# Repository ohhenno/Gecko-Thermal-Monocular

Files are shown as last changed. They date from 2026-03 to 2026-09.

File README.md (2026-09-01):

# Gecko 256

The Gecko is an open-source thermal monocular featuring the Mini2 256p thermal core, digital zoom, and video recording capability. Special thanks to LupasWorax Gremlin and [JacobOTW](https://github.com/Jacob-OTW/BCOTI/tree/V2_Beta?tab=readme-ov-file) .

The hardware platform is built around:
- HdanieeCamera Core
- ESP32 UART/GPIO Controls  
- 0.39" micro OLED display  
- NP18 lens  

---

## 🧩 Parts Checklist

| ✓ | Component | Notes | Price (USD) | Link |
|--|---|---|---|---|
| ☐ | **Thermal Core (Mini2 256)** | Gecko Variant | $120 | https://shorturl.at/Mn3Rv |
| ☐ | **Thermal Core (P6 640)** | TAC-640 Variant | $420 | https://www.hdaniee.com/p6-uc-series.html |
| ☐ | **0.39" OLED Display** | Main display + driver | $110 | https://www.aliexpress.us/item/3256809119244467.html |
| ☐ | **NP18 Lens** | Optics | $60 | https://www.aliexpress.us/item/3256808208343549.html |
| ☐ | **ESP32-C3** | Main controller | $1 | https://www.aliexpress.us/item/3256808855552297.html |
| ☐ | **5V Boost Converter** | Steps battery → 5V | $2 | https://www.amazon.com/dp/B0836J8LR4 |
| ☐ | **18350 Battery** | Power source | $15 | https://amazon.com/dp/B07QDDS64F |
| ☐ | **Battery Contacts** | Spring terminals | $5 | https://amazon.com/dp/B0FSDNXKJY |
| ☐ | **Rotary Pot (20k)** | Brightness / contrast control | $2 | https://www.aliexpress.us/item/3256803337433740.html |
| ☐ | **Buttons (x3)** | Zoom / Mode / Record | $2 | https://www.aliexpress.us/item/3256806708603327.html |
| ☐ | **Runcam DVR (Optional)**  | Recording | $30 | https://www.aliexpress.us/item/3256809185467125.html |
| ☐ | **MicroSD Extender** | Required for DVR | $10 | https://amazon.com/dp/B0D7YZ5PG3 |
| ☐ | **M2.5 x 6 Bolts** | Mounting hardware | $2 | https://amazon.com/dp/B0GCSRG1WD |
| ☐ | **Heat Set Inserts** | Threaded inserts | $10 | [https://amazon.com/dp/B0D7YZ5PG3](https://shorturl.at/LMswM) |
| ☐ | **Silicone Wire** | Internal wiring | $6 | https://amazon.com/dp/B01KQ2JNLI |

---

### 💰 Estimated Build Cost

- **Gecko (Mini2 build):**  
  $335  

- **TAC-640 (P6 build):**  
  $635  

- **With DVR (adds DVR + MicroSD extender):**  
  $40  

---

## 📷 Device Overview







---

## ⚡ Power-On Behavior

Turn the potentiometer fully clockwise to power on the device.

- **System initialization time:** ~6 seconds  

### Default Image Settings
- Brightness: 70  
- Contrast: 64  
- Enhancement: 80  
- Denoise: 40  
- Zoom: 1.0×  
- Palette: White Hot  
- Automatic calibration (NUC): every 60 seconds  

---

## 🎮 Controls Overview

### Buttons
- **Zoom Button** — front-most button  
- **Multi Button** — center button  
- **Record Button** — rear button  

### Analog Control
- **Rotary Knob (Potentiometer)** — controls brightness and contrast  

---

## 🔍 Zoom & OLED Brightness

### Zoom Control
- **Single Press:**  
  Cycles zoom levels  
  `1.0× → 2.0× → 4.0× → repeat`

### OLED Brightness
- **Hold Zoom (~1 second):**  
  Increase brightness (continues stepping every ~1s)

- **Double Tap Zoom:**  
  Decrease brightness  

---

## 🎨 Palette Control

- **Multi Button (Short Press):**  
  Cycles through palettes:
  - White Hot  
  - Black Hot  
  - Rainbow  
  - Green Hot  
  - Red Hot  
  - Iron Red  

---

## 🎛️ Image Adjustment

- **Knob (Normal):**  
  Adjust brightness  

- **Hold Multi + Turn Knob:**  
  Adjust contrast  

---

## 🔴 Recording Feedback

- **Record Button:**  
  Toggles external DVR recording  

### Visual Feedback (Palette Flash)
- Start recording → **3 slow flashes**  
- Stop recording → **5 fast flashes**  

---

## 🧊 Calibration (NUC)

### Manual Calibration
- Hold **Multi button for 3 seconds**
  - Image briefly freezes  
  - Sensor recalibrates  
  - Fixed-pattern noise reduced  

### Automatic Calibration
- Runs every **60 seconds**  

---

## ⚡ Quick Reference

<table>
<tr>
<td valign="top">

| Action | Result |
|---|---|
| Zoom press | Change zoom |
| Zoom hold | Increase OLED brightness |
| Zoom double tap | Decrease OLED brightness |
| Multi press | Cycle palettes |
| Multi hold | Trigger NUC calibration |
| Knob | Adjust brightness |
| Multi + knob | Adjust contrast |
| Record press | Toggle recording |

</td>
<td valign="top">

<pre>
        Button Diagram

        [ Camera Side ]
               ↑
           ┌─────────┐
           │   ◉     │   ZOOM (Front)
           │         │
           │   ◉     │   MODE / MULTI
           │         │
           │   ◉     │   RECORD (Rear)
           └─────────┘
               ↓
        [ Ocular Side ]
</pre>

</td>
</tr>
</table>

---

## 🧠 System Diagram / Reference





---

Battery Life 1hr 26mins:


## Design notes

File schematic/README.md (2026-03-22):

The DVR is optional, its reduces the battery life by a non zero amount.

Pay special attention when wiring up the battery ground and general ground they are different nets.

Pay special attention of you are using a different 10 pin connector for the OLED board as they could be flipped.



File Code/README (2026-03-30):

Flash the ESP32-C3 Super Mini via https://esptool.spacehuhn.com/

Hold BOOT
Plug in USB
Release BOOT

Click Connect → select ESP32 serial port

Load files with offsets:

0x0 → bootloader.bin
0x8000 → partition-table.bin
0x10000 → gecko.bin

Click ERASE
Click PROGRAM

Done.

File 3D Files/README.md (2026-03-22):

Print these at 0.16 layer height in PETG for best results.



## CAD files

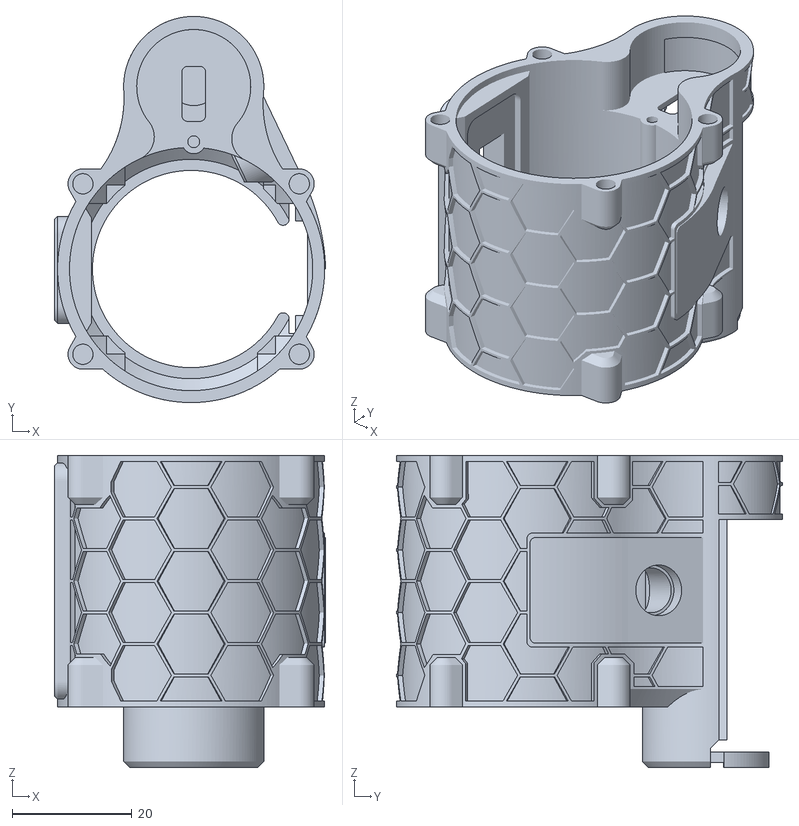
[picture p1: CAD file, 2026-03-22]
3D Files/thermal main body.stl
45.4 x 64.6 x 52.2

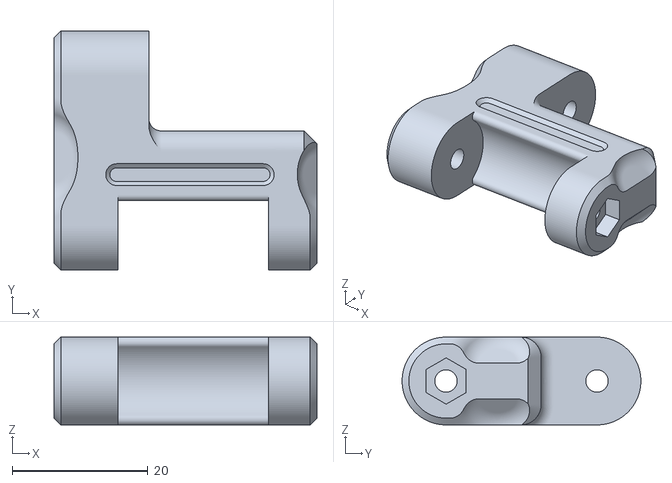
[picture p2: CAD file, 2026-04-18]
3D Files/J_ARM_elbow.stl
38.7 x 35.1 x 12.9

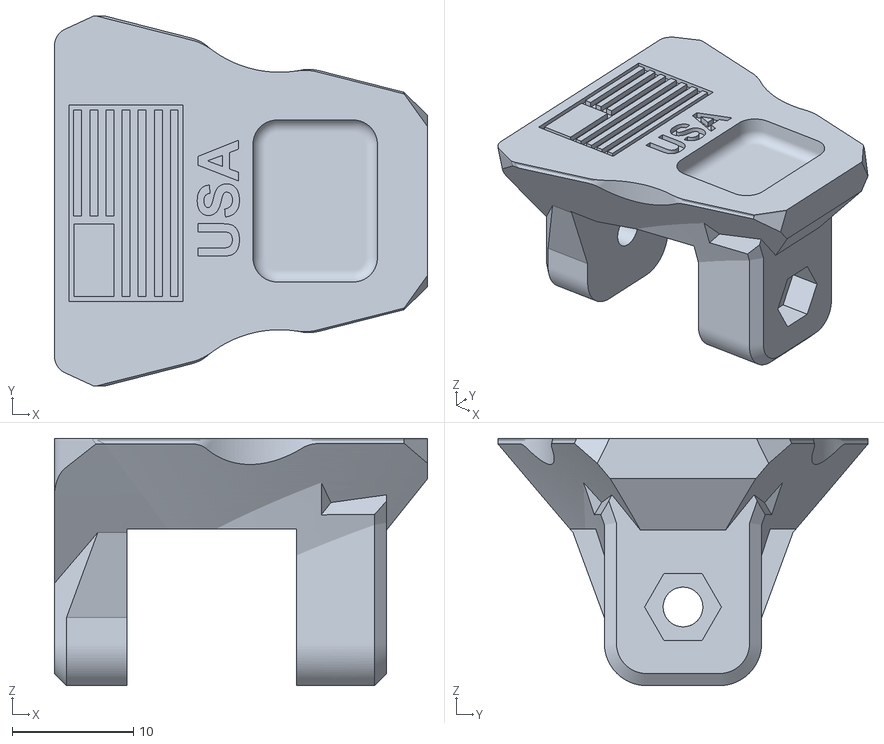
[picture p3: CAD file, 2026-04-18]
3D Files/J_ARM_dovetail.stl
30.8 x 30.6 x 20.4

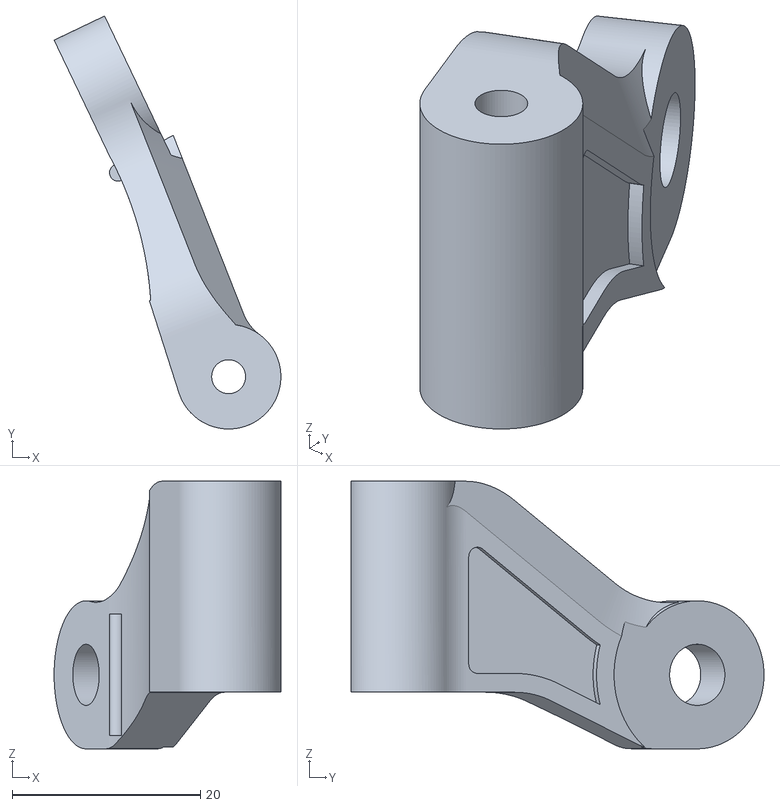
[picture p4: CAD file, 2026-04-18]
3D Files/J_ARM.stl
24.1 x 43.8 x 28.4

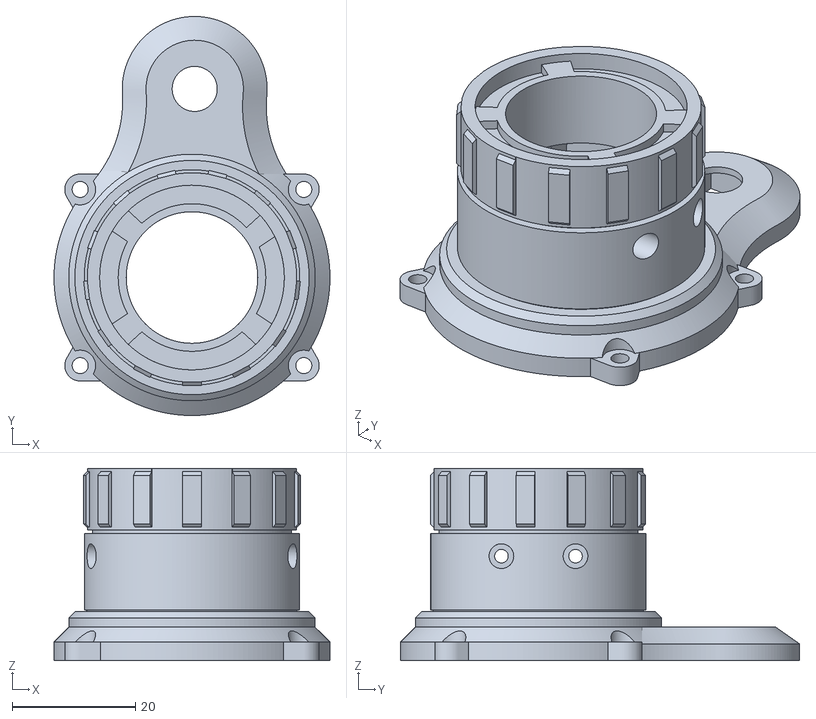
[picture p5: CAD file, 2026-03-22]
3D Files/thermal body camera.stl
44.7 x 64.6 x 31.1

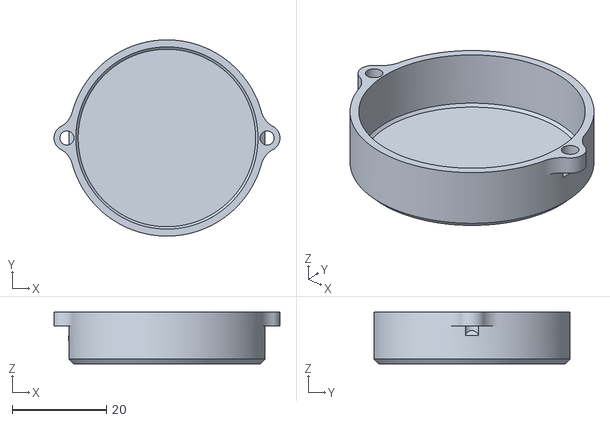
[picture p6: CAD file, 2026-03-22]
3D Files/lens cap.stl
48.0 x 41.7 x 11.0

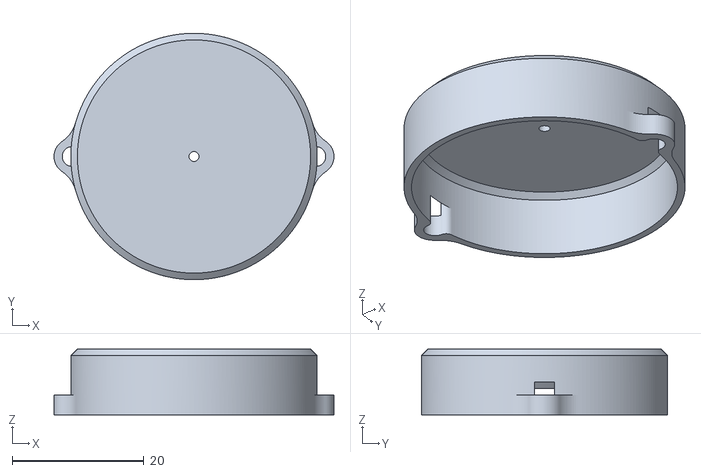
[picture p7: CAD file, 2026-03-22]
3D Files/camera cap.stl
42.4 x 37.3 x 10.0

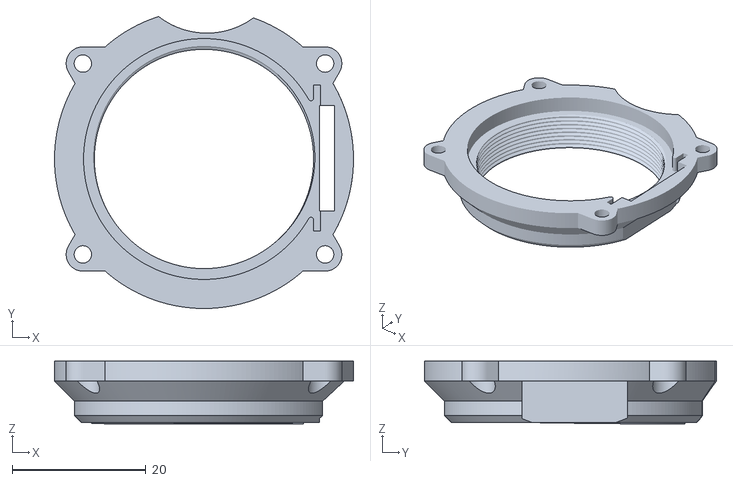
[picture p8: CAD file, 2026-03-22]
3D Files/thermal body np18.stl
44.7 x 43.6 x 9.39

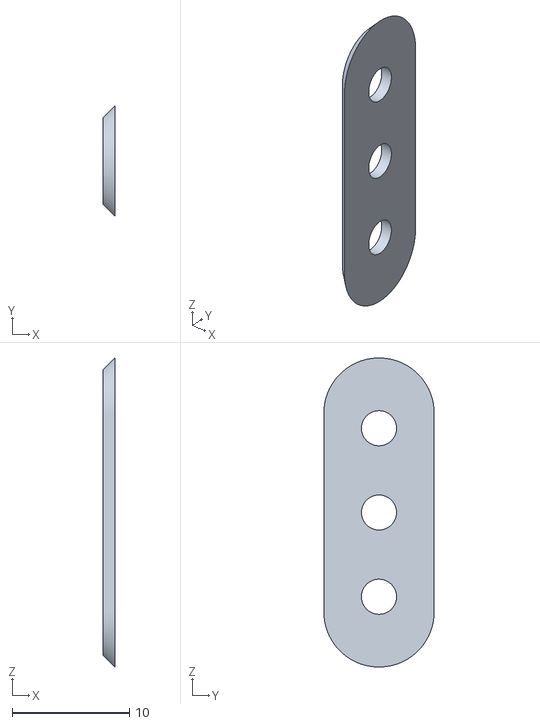
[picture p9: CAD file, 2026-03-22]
3D Files/button cover.stl
1.00 x 9.43 x 26.4

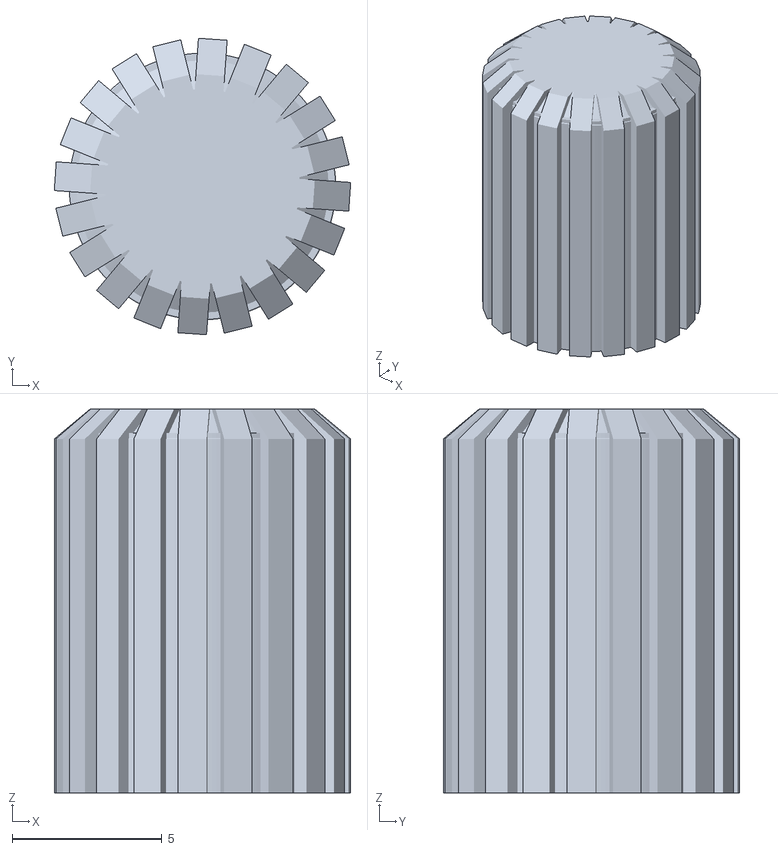
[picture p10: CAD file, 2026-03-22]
3D Files/knob.stl
9.88 x 9.88 x 12.8

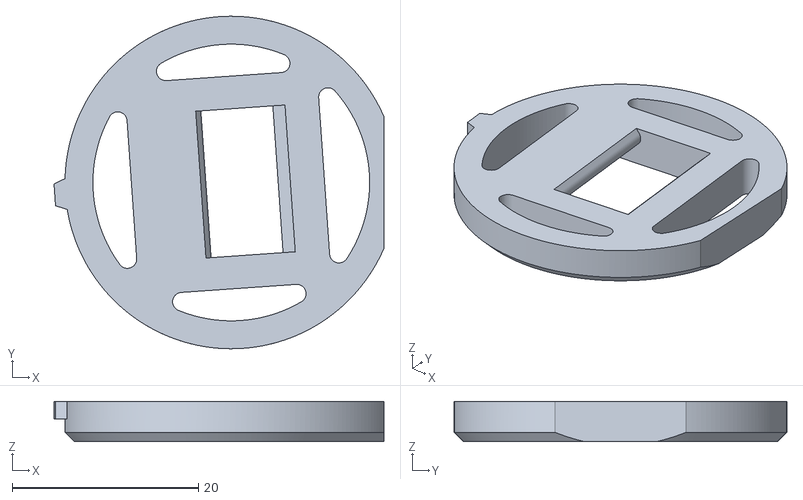
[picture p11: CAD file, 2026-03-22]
3D Files/oled frame.stl
35.4 x 35.7 x 4.31

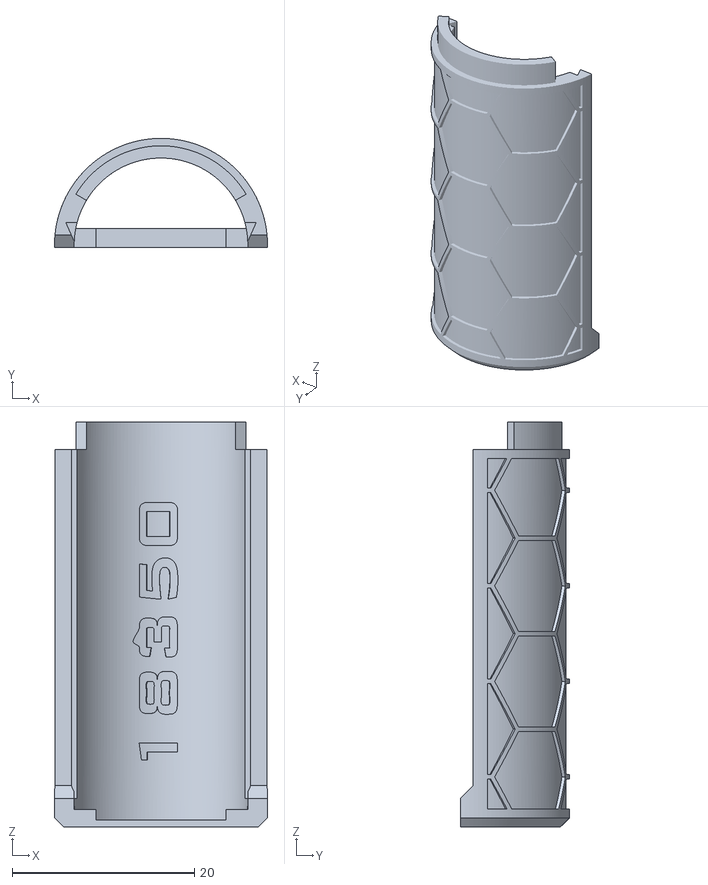
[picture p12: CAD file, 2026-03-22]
3D Files/battery cover.stl
23.4 x 12.0 x 44.5

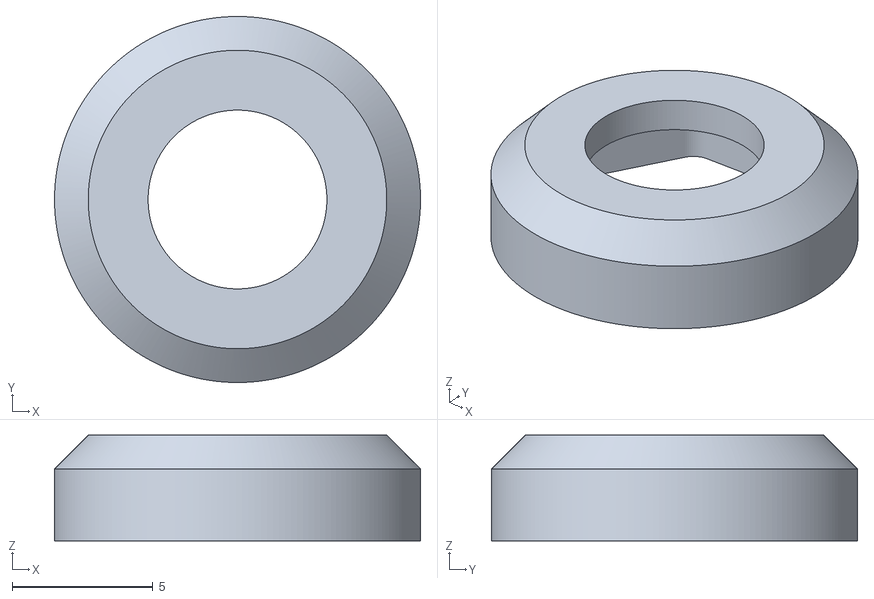
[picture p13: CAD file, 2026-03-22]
3D Files/knob cover.stl
13.0 x 13.0 x 3.75

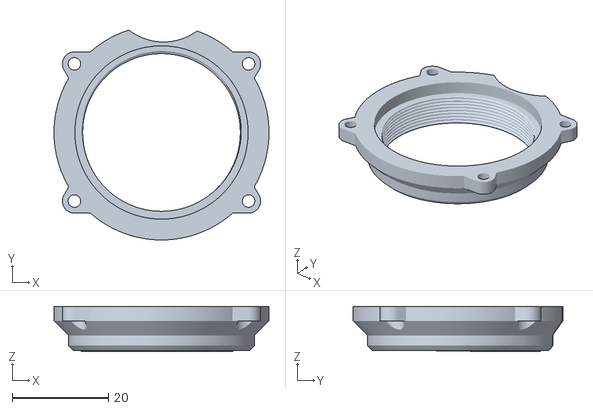
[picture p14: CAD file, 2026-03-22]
3D Files/thermal body np18 (no DVR).stl
44.7 x 43.6 x 9.39

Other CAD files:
3D Files/oled frame (no DVR).stl
3D Files/M3 screws enjoyers/thermal main body M3.3mf
3D Files/M3 screws enjoyers/thermal body np18 M3 (1).3mf
3D Files/M3 screws enjoyers/thermal body np18 (no DVR) M3.3mf
3D Files/M3 screws enjoyers/thermal body camera M3.3mf

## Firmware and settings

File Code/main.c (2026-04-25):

#include <stdio.h>
#include <stdbool.h>
#include <stdint.h>
#include <stdlib.h>

#include "freertos/FreeRTOS.h"
#include "freertos/task.h"

#include "esp_timer.h"

#include "driver/gpio.h"

#include "Mini2.h"

#include "esp_adc/adc_oneshot.h"

// ---------------- GPIO ----------------
#define UART_TX GPIO_NUM_1
#define UART_RX GPIO_NUM_2

#define MULTI_BTN GPIO_NUM_10
#define ZOOM_BTN GPIO_NUM_9
#define FLASH_BTN GPIO_NUM_7

#define BRIGHT_UP GPIO_NUM_5
#define BRIGHT_DOWN GPIO_NUM_6

// ---------------- TIMING ----------------
#define CLICK_MAX_US        250000
#define DOUBLE_CLICK_US     350000

// ---------------- CAMERA ----------------
Mini2_t cam = {
    .uart_port = UART_NUM_1,
    .uart_tx = UART_TX,
    .uart_rx = UART_RX,
    .variant = Mini2_256
};

// ---------------- STATE ----------------
int zoom_steps[3] = {10, 20, 60};
int zoom_index = 0;

bool palette_state = false;

// ---------------- ZOOM ----------------
bool last_zoom_btn = false;
bool zoom_hold_active = false;
bool zoom_double_wait = false;

int64_t zoom_press_time = 0;
int64_t last_release_time = 0;
int64_t last_repeat_time = 0;

// ---------------- MULTI ----------------
bool last_multi = false;
int64_t multi_press_time = 0;
int64_t last_multi_click = 0;
bool multi_hold_triggered = false;

// ---------------- FLASH ----------------
bool last_flash = false;
bool flash_mode = false;

//------------ADC---------------
#define POTI_PIN GPIO_NUM_4

int brightness = 60;
int contrast = 50;
// ---------------- PRESETS ----------------
#define PRESET_COUNT 3
int current_mode = 0;

value_preset_t presets[PRESET_COUNT] = {
    {
        .preset_en = true,
        .pseudo_color = WHOT,
        .scene_mode = Highlight,
        .contrast = 100,
        .edge_enhancment_gear = 1,
        .detail_enhancement_gear = 55,
        .burn_protection_en = true,
        .auto_shutter_en = true,
        .breathing = false
    },
    {
        .preset_en = true,
        .pseudo_color = WHOT,
        .scene_mode = HighContrast,
        .contrast = 100,
        .edge_enhancment_gear = 1,
        .detail_enhancement_gear = 55,
        .burn_protection_en = true,
        .auto_shutter_en = true,
        .breathing = false
    },
    {
        .preset_en = true,
        .pseudo_color = WHOT,
        .scene_mode = Outline,
        .contrast = 100,
        .edge_enhancment_gear = 1,
        .detail_enhancement_gear = 50,
        .burn_protection_en = true,
        .auto_shutter_en = true,
        .breathing = false
    }
};

// ---------------- HELPERS ----------------
static inline void pulse_gpio(gpio_num_t pin, int ms)
{
    gpio_set_level(pin, 0);
    vTaskDelay(pdMS_TO_TICKS(ms));
    gpio_set_level(pin, 1);
}

void run_flash_pattern()
{
    if (!flash_mode)
    {
        for (int i = 0; i < 3; i++)
        {
            Mini2_set_crosshair(&cam, false);
            vTaskDelay(pdMS_TO_TICKS(120));
            Mini2_set_crosshair(&cam, true);
            vTaskDelay(pdMS_TO_TICKS(180));
        }
    }
    else
    {
        for (int i = 0; i < 5; i++)
        {
            Mini2_set_crosshair(&cam, false);
            vTaskDelay(pdMS_TO_TICKS(40));
            Mini2_set_crosshair(&cam, true);
            vTaskDelay(pdMS_TO_TICKS(60));
        }
    }
    flash_mode = !flash_mode;
}

// 🔧 SAFE PRESET APPLY (ONLY VALID FUNCTIONS)
void apply_preset(int mode)
{
    value_preset_t *p = &presets[mode];

    if (!p->preset_en) return;

    // Scene mode (this is the BIG one)
    Mini2_set_scene_mode(&cam, p->scene_mode);

    // Contrast
    Mini2_set_contrast(&cam, p->contrast);

    // Edge enhancement (your driver spelling)
    Mini2_set_edge_enhancment(&cam, p->edge_enhancment_gear);

    // Detail enhancement
    Mini2_set_detail_enhancement(&cam, p->detail_enhancement_gear);

    // Burn protection
    Mini2_set_burn_protection(&cam, p->burn_protection_en);

    // Auto shutter / NUC behavior
    Mini2_set_auto_shutter(&cam, p->auto_shutter_en);

    // IMPORTANT: Palette stays user-controlled
    Mini2_set_color_pallet(&cam, palette_state ? BHOT : WHOT);
}

// ---------------- LOOP ----------------
void loop_task(void *pv)
{
    int64_t last_crosshair = 0;

    adc_unit_t unit;
    adc_channel_t ch;
    adc_oneshot_io_to_channel(POTI_PIN, &unit, &ch);

    adc_oneshot_unit_handle_t adc;
    adc_oneshot_unit_init_cfg_t cfg = {.unit_id = unit};
    adc_oneshot_new_unit(&cfg, &adc);

    adc_oneshot_chan_cfg_t ch_cfg = {
        .bitwidth = ADC_BITWIDTH_DEFAULT,
        .atten = ADC_ATTEN_DB_12};
    adc_oneshot_config_channel(adc, ch, &ch_cfg);

    int last_adc = 0;

    while (1)
    {
        int64_t now = esp_timer_get_time();

        bool zoom = !gpio_get_level(ZOOM_BTN);
        bool multi = !gpio_get_level(MULTI_BTN);
        bool flash = !gpio_get_level(FLASH_BTN);

        // ================= ZOOM =================
        if (zoom && !last_zoom_btn)
        {
            zoom_press_time = now;
            zoom_hold_active = false;

            zoom_index = (zoom_index + 1) % 3;
            int zoom_val = zoom_steps[zoom_index];

            Mini2_set_centre_zoom(&cam, zoom_val);

            if (zoom_val == 10)
                Mini2_set_crosshair(&cam, true);
            else
                Mini2_set_crosshair(&cam, false);
        }

        if (!zoom && last_zoom_btn)
        {
            int64_t dt = now - zoom_press_time;

            if (dt < 250000)
            {
                if (zoom_double_wait && (now - last_release_time < 400000))
                {
                    pulse_gpio(BRIGHT_DOWN, 60);
                    zoom_double_wait = false;
                }
                else
                {
                    zoom_double_wait = true;
                    last_release_time = now;
                }
            }

            zoom_hold_active = false;
        }

        if (zoom)
        {
            int64_t held = now - zoom_press_time;

            if (!zoom_hold_active && held > 1000000)
            {
                pulse_gpio(BRIGHT_UP, 60);
                zoom_hold_active = true;
                last_repeat_time = now;
            }

            if (zoom_hold_active && (now - last_repeat_time > 1000000))
            {
                pulse_gpio(BRIGHT_UP, 60);
                last_repeat_time = now;
            }
        }

        if (zoom_double_wait && (now - last_release_time > 500000))
            zoom_double_wait = false;

        last_zoom_btn = zoom;

        // ================= MULTI =================
        if (multi && !last_multi)
            {
                multi_press_time = now;
            }

            if (!multi && last_multi)
            {
                int64_t dt = now - multi_press_time;

                if (dt < CLICK_MAX_US)
                {
                    if ((now - last_multi_click) < DOUBLE_CLICK_US)
                    {
                        // DOUBLE CLICK → PALETTE
                        palette_state = !palette_state;
                        Mini2_set_color_pallet(&cam, palette_state ? BHOT : WHOT);
                        last_multi_click = 0;
                    }
                    else
                    {
                        last_multi_click = now;
                    }
                }
            }

            // HOLD → NUC (ONE SHOT)
            if (multi && !multi_hold_triggered && (now - multi_press_time > 3000000))
            {
                Mini2_NUC(&cam);
                multi_hold_triggered = true;
            }

            // SINGLE CLICK
            if (last_multi_click && (now - last_multi_click > DOUBLE_CLICK_US))
            {
                current_mode = (current_mode + 1) % PRESET_COUNT;
                apply_preset(current_mode);
                last_multi_click = 0;
            }

            // 🔥 RELEASE DETECT (correct place)
            if (!multi && last_multi)
            {
                multi_hold_triggered = false;
            }

            // 🔥 UPDATE STATE LAST

            last_multi = multi;

        // ================= FLASH =================
        if (flash && !last_flash)
        {
            run_flash_pattern();
        }
        last_flash = flash;

        // ================= CROSSHAIR KEEP ALIVE =================
        if (zoom_steps[zoom_index] == 10 && (now - last_crosshair > 200000))
        {
            Mini2_set_crosshair(&cam, true);
            last_crosshair = now;
        }

        // ================= ADC =================
        int adc_raw;
        adc_oneshot_read(adc, ch, &adc_raw);

        // smooth
        adc_raw = (adc_raw * 2 + last_adc) / 3;

        if (abs(adc_raw - last_adc) > 10)
        {
            if (multi)
            {
                // MULTI HELD → CONTRAST
                contrast = 20 + (adc_raw * 80) / 4095;
                Mini2_set_contrast(&cam, contrast);
            }
            else
            {
                // NORMAL → BRIGHTNESS (Mini2 side, not OLED)
                brightness = 20 + (adc_raw * 80) / 4095;
                Mini2_set_brightness(&cam, brightness);
            }
        }

            last_adc = adc_raw;

        vTaskDelay(pdMS_TO_TICKS(8));
    }
}

// ---------------- MAIN ----------------
void app_main(void)
{
    gpio_config_t in = {
        .mode = GPIO_MODE_INPUT,
        .pin_bit_mask =
            (1ULL << ZOOM_BTN) |
            (1ULL << MULTI_BTN) |
            (1ULL << FLASH_BTN),
        .pull_up_en = GPIO_PULLUP_ENABLE};
    gpio_config(&in);

    gpio_config_t out = {
        .pin_bit_mask = (1ULL << BRIGHT_UP) | (1ULL << BRIGHT_DOWN),
        .mode = GPIO_MODE_OUTPUT_OD};
    gpio_config(&out);

    gpio_set_level(BRIGHT_UP, 1);
    gpio_set_level(BRIGHT_DOWN, 1);

    Mini2_init(&cam);
    vTaskDelay(pdMS_TO_TICKS(2000));

    Mini2_set_color_pallet(&cam, WHOT);
    Mini2_set_centre_zoom(&cam, 10);
    Mini2_set_crosshair(&cam, true);

    xTaskCreate(loop_task, "loop", 8192, NULL, 5, NULL);
}

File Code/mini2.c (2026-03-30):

#include "Mini2.h"

uint16_t crc16_xmodem(uint8_t* data, size_t len) {
    uint16_t crc = 0;
    for (int i=0; i<len; i++) {
        crc ^= (data[i] << 8);
        for (int j=0; j<8; j++) {
            if (crc & 0x8000) {
                crc = (crc << 1) ^ 0x1021;
            } else {
                crc <<= 1;
            }
        }
    }
    return crc;
}

void Mini2_init(Mini2_t* cam) {
    uart_config_t uart_config = {
        .baud_rate = 115200,
        .data_bits = UART_DATA_8_BITS,
        .parity = UART_PARITY_DISABLE,
        .stop_bits = UART_STOP_BITS_1,
        .flow_ctrl = UART_HW_FLOWCTRL_DISABLE,
        .source_clk = UART_SCLK_DEFAULT,
    };

    ESP_ERROR_CHECK(uart_driver_install(cam->uart_port, 2048, 0, 0, NULL, 0));
    ESP_ERROR_CHECK(uart_param_config(cam->uart_port, &uart_config));
    ESP_ERROR_CHECK(uart_set_pin(cam->uart_port, cam->uart_tx, cam->uart_rx, -1, -1));
}

esp_err_t Mini2_write_command(Mini2_t* cam, uint8_t* cmd, size_t len) {
    uint8_t full_cmd[] = {0x55, 0x43, 0x49, 0x12, 0x00, 0x00 /*command class*/, 0x00 /*command index*/, 0x00 /*sub command*/, 0x00 /*reserved*/, 0x00, 0x00, 0x00, 0x00 /*4byte Parameter1*/, 0x00, 0x00, 0x00, 0x00 /*4byte Parameter2*/, 0x00, 0x00 /*Read length, 0 when writing*/, 0x00, 0x00 /*2btyes Reserved*/, 0x00, 0x00 /*2byte crc16 xmodem*/};

    if (len > 16) {
        ESP_LOGE(Mini2_TAG, "command length may not be longer than 16bytes");
        return ESP_FAIL;
    }

    memcpy(full_cmd + 5, cmd, len);
    uint16_t checksum = crc16_xmodem(full_cmd + 5, 16);
    memcpy(full_cmd + 21, &checksum, 2);

    ESP_LOG_BUFFER_HEXDUMP(Mini2_TAG, full_cmd, sizeof(full_cmd), ESP_LOG_INFO);
    
    for (int i=0; i < sizeof(full_cmd); i++) {
        int bytes_written = uart_write_bytes(cam->uart_port, full_cmd + i, 1);
        if (bytes_written == -1) {
            ESP_LOGE(Mini2_TAG, "Failed to write byte%d command to UART", i);
            return ESP_FAIL;
        }   
    }

    return ESP_OK;
}

esp_err_t Mini2_read_command(Mini2_t* cam, uint8_t* cmd, size_t len, uint8_t* out_buf, size_t* out_len) {
    esp_err_t err_code;

    uart_flush(cam->uart_port);
    err_code = Mini2_write_command(cam, cmd, len);
    if (err_code != ESP_OK) {
        return err_code;
    }
    int bytes_read = uart_read_bytes(cam->uart_port, out_buf, *out_len, pdMS_TO_TICKS(200));
    if (bytes_read < 0) {
        return ESP_FAIL;
    }

    ESP_LOG_BUFFER_HEXDUMP("UART_READ", out_buf, bytes_read, ESP_LOG_INFO);

    *out_len = bytes_read;
    return ESP_OK;
}

esp_err_t Mini2_get_flip_mode(Mini2_t* cam, enum FlipMode* flip_mode_out) {
    uint8_t rx_buffer[10];
    size_t len = sizeof(rx_buffer);

    uint8_t cmd[] = {0x10, 0x10, 0x83, 0x00, 0x00, 0x00, 0x00, 0x00, 0x00, 0x00, 0x00, 0x00, 0x01};
    esp_err_t err_code = Mini2_read_command(cam, cmd, sizeof(cmd), rx_buffer, &len);
    if (err_code != ESP_OK) {
        return err_code;
    }
    
    if (!(rx_buffer[0] == 0xBE && rx_buffer[1] == 0xAA && rx_buffer[8] == 0xEB && rx_buffer[9] == 0xAA)) {
        return ESP_FAIL;
    }

    *flip_mode_out = (enum FlipMode)rx_buffer[5];
    return ESP_OK;
}

esp_err_t Mini2_set_color_pallet(Mini2_t* cam, enum PseudoColor pseudo_color) {
    uint8_t cmd[] = {0x10, 0x03, 0x45, 0x00, 0x00, pseudo_color};
    return Mini2_write_command(cam, cmd, sizeof(cmd));
}

esp_err_t Mini2_set_scene_mode(Mini2_t* cam, enum SceneMode scene_mode) {
    uint8_t cmd[] = {0x10, 0x04, 0x42, 0x00, scene_mode};
    return Mini2_write_command(cam, cmd, sizeof(cmd));
}

esp_err_t Mini2_set_flip_mode(Mini2_t* cam, enum FlipMode flip_mode) {
    uint8_t cmd[] = {0x10, 0x10, 0x43, 0x00, flip_mode};
    return Mini2_write_command(cam, cmd, sizeof(cmd));
}

esp_err_t Mini2_set_analog_video_format(Mini2_t* cam, enum AnalogVideoFormat av_format) {
    uint8_t cmd[] = {0x10, 0x10, 0x4A, 0x00, 0x01, av_format};
    return Mini2_write_command(cam, cmd, sizeof(cmd));
}

esp_err_t Mini2_get_analog_video_format(Mini2_t* cam, enum AnalogVideoFormat* av_format_out) {
    uint8_t rx_buffer[11];
    size_t len = sizeof(rx_buffer);

    uint8_t cmd[] = {0x10, 0x10, 0x8a, 0x00, 0x00, 0x00, 0x00, 0x00, 0x00, 0x00, 0x00, 0x00, 0x02};
    esp_err_t err_code = Mini2_read_command(cam, cmd, sizeof(cmd), rx_buffer, &len);
    if (err_code != ESP_OK) {
        return err_code;
    }

    if (!(rx_buffer[0] == 0xBE && rx_buffer[1] == 0xAA && rx_buffer[9] == 0xEB && rx_buffer[10] == 0xAA)) {
        return ESP_FAIL;
    }

    *av_format_out = (enum AnalogVideoFormat)rx_buffer[6];
    return ESP_OK;
}

esp_err_t Mini2_set_digital_video_format(Mini2_t* cam, bool enabled, enum DigitalVideoFormat video_format, enum DetectorRefreshRate fps) {
    uint8_t cmd[] = {0x10, 0x10, 0x46, 0x00, (uint8_t)enabled, (uint8_t)video_format, (uint8_t)fps};
    return Mini2_write_command(cam, cmd, sizeof(cmd));
}

esp_err_t Mini2_save_video(Mini2_t* cam) {
    uint8_t cmd[] = {0x10, 0x10, 0x49};
    return Mini2_write_command(cam, cmd, sizeof(cmd));
}

esp_err_t Mini2_set_brightness(Mini2_t* cam, uint8_t brightness) {
    if (brightness > 100) {
        ESP_LOGE(Mini2_TAG, "Brightness must be <= 100");
        return ESP_FAIL;
    }
    uint8_t cmd[] = {0x10, 0x04, 0x47, 0x00, brightness};
    return Mini2_write_command(cam, cmd, sizeof(cmd));
}

esp_err_t Mini2_set_contrast(Mini2_t* cam, uint8_t contrast) {
    if (contrast > 100) {
        ESP_LOGE(Mini2_TAG, "Contrast must be <= 100");
        return ESP_FAIL;
    }
    uint8_t cmd[] = {0x10, 0x04, 0x4A, 0x00, contrast};
    return Mini2_write_command(cam, cmd, sizeof(cmd));
}

esp_err_t Mini2_set_edge_enhancment(Mini2_t* cam, uint8_t gear) {
    if (gear > 2) {
        ESP_LOGE(Mini2_TAG, "Edge enhancment gear must be <= 2");
        return ESP_FAIL;
    }
    uint8_t cmd[] = {0x10, 0x04, 0x4E, 0x00, gear};
    return Mini2_write_command(cam, cmd, sizeof(cmd));
}

esp_err_t Mini2_set_detail_enhancement(Mini2_t* cam, uint8_t gear) {
    if (gear > 100) {
        ESP_LOGE(Mini2_TAG, "Detail enhancement gear must be <= 100");
        return ESP_FAIL;
    }
    uint8_t cmd[] = {0x10, 0x04, 0x45, 0x00, gear};
    return Mini2_write_command(cam, cmd, sizeof(cmd));
}

esp_err_t Mini2_set_burn_protection(Mini2_t* cam, bool enabled) {
    uint8_t cmd[] = {0x10, 0x03, 0x4B, 0x00, (uint8_t)enabled};
    return Mini2_write_command(cam, cmd, sizeof(cmd));
}

esp_err_t Mini2_set_shutter_position(Mini2_t* cam, bool open) {
    uint8_t cmd[] = {0x01, 0x0F, 0x45, 0x00, (uint8_t)open};
    return Mini2_write_command(cam, cmd, sizeof(cmd));
}

esp_err_t Mini2_set_auto_shutter(Mini2_t* cam, bool enabled) {
    uint8_t cmd[] = {0x10, 0x02, 0x41, 0x00, (uint8_t)enabled};
    return Mini2_write_command(cam, cmd, sizeof(cmd));
}
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

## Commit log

2026-04-18 Rename DOVETAIL (2).stl to J_ARM_dovetail.stl
    [J_ARM_dovetail.stl]
2026-04-18 Rename L-ARM MONO.stl to J_ARM_elbow.stl
    [J_ARM_elbow.stl]
